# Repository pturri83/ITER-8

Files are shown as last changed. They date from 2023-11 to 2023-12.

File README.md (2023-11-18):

# DB6502 - Dawid Buchwald's 6502 Computer

This repository contains all the work in progress during my build of Ben Eater's inspired 6502 8-bit computer similar to typical machines of the early 1980s. If you haven't seen Ben's videos, I would strongly suggest you start there:

[Ben Eater's 6502 project](https://eater.net/6502)

As stated above, this build is not 100% compatible with what Ben had done - and for a reason, described in next section.

If I had to explain shortly "what it is", the answer would be: simple, yet easy to expand, 8-bit CPU based computer designed and built with one goal only: to use it as a learning and tinkering platform to understand how computers really work. You can use it for simple things like understanding buses, clock cycles, instruction execution, but it also demonstrates more complex concepts like interrupts, interfaces to external components and device handling. More on that below. Everything, hopefully, is simple enough to wrap your head around by one person in couple of weeks.

## Why build something different

[Ben's videos](https://www.youtube.com/playlist?list=PLowKtXNTBypFbtuVMUVXNR0z1mu7dp7eH) on 6502 computer are absolutely awesome - it's one of the best sources in the whole Internet explaining how any computer works. The build he introduced is probably sufficient for most of the things you might ever want to build, and yet I decided to deviate from his design.

The rationale behind this project is pretty simple - the best way to test your understanding of certain subject is to try to expand on what you have learned. You never know if you understood something until you test it by introducing changes to original design - and I used this approach in this project to learn a lot. It was my first proper electronics project, so I would like to apologize for any mistakes. If you think something is off or could have been done differently - please go ahead and raise issue for the repo! All improvements are welcome!

## Why would you bother using DB6502 instead of BE6502

Basically, it gives you almost all the flexibility of Ben's buid without the hassle of breadboard connections for the critical components. You can still run all of Ben's programs (using second VIA port), but the days of looking for loose wire between RAM and CPU are over :) You can, obviously, still experiment with peripherals and breadboard connections using extension port and second VIA.

On top of that you get additional features like extra screen (via onboard connector), keyboard for more versatile input and finally all-in-one serial over USB terminal. You also get easy to use software ready to be installed on the machine to jumpstart your tinkering. When using bootloader you don't even have to flash the EEPROM more than once!

**Important note:** All of the content here is, and always will be open source and free to use, and I don't intend to make any profit out of it. The only way I get anything at all (and it's only small commission to be used for future PCBWay orders) is when you order my boards from PCBWay using the links posted below, but you are welcome to grab these gerber files and order the boards from another provider, or even from PCBWay, just by uploading gerbers to your account, if you don't want me to get the commission :)

## What is different

Compared to Ben's 6502 build I introduced the following changes:

1. Added [automatic power-up reset circuitry](Schematics/README.md#automatic-power-on-reset),
2. Changed [address decoder logic](Schematics/README.md#address-decoder-change) (**very important from compatibility perspective**),
3. Changed [LCD interface](Schematics/README.md#lcd-interface-change) from 8-bit to 4-bit (**very important from compatibility perspective**),
4. Added [additional VIA chip](Schematics/README.md#extra-via-chip) to provide easy expansion of the system,
5. Added [ACIA chip for serial communication](Schematics/README.md#extra-acia-chip-for-serial-communication),
6. Added (**optional - more on that later**) [USB-UART interface](Schematics/README.md#extra-usb-uart-interface-chip) for easy connectivity with PC,
7. Added [PS/2 keyboard port and ATtiny4313-based keyboard controller](Schematics/README.md#ps2-keyboard-interface-and-attiny4313-based-controller) to provide proper replacement for five pushbuttons in Ben's design,
8. Added [expansion port](Schematics/README.md#expansion-port) (not really deviation from Ben's build, save for one detail - unlike Ben's build, my version can support various interrupt sources, including the expansion port),
9. Modified [clock module](Schematics/README.md#modified-clock-module) (external),
10. Changed [compilator from VASM to CC65](Schematics/README.md#migration-from-vasm-to-cc65),
11. Added [simple way to choose clock source](Schematics/README.md#clock-input).

You might be wondering if this means that you can't run Ben's programs on DB6502 - and the answer is **YES YOU CAN**. Indeed, some changes to the code are necessary, but thanks to the additional VIA chip and with some changes to the addressing mode you can run any program from Ben's videos. If you want to use LCD in 8-bit mode, you can also use the additional VIA for it, ignoring the built-in LCD connector.

By the way, the opposite is also true - **you can compile and run my programs on Ben's computer**. There are special compilation flags that enable usage of Ben's address decoder. I will describe this in more detail in software section.

Detailed description and rationale for each change is discussed in [Schematics README](Schematics/README.md).

## Getting started

Okay, so it should be pretty clear what this project is about, so how to start playing with it? That really depends on what you decide to do:

- Stick with BE6502 and just use subset of provided software (either to install it in EEPROM, or just use it as reference for your own hacking),
- Build your own breadboard design based on this one with any modifications you can think of,
- Order PCBs of DB6502, solder the components and run provided software to see how it works and get started with your own designs.

To start from scratch it's actually easiest to select last option - after some waiting you will end up having pretty solid base to extend your design on.

### Using provided software with BE6502

If you decide to go down that route, head straight to the `Software` folder, where you will find several programs either identical or similar to what Ben has shown in his videos, but built with much more versatile toolchain.

If you want to read more, go ahead and read [Software folder](Software/README.md) section. Make sure to check out the [building software](Software/README.md#building-software) subsection, as it explains how to compile programs to run on BE6502 directly.

### Build your own breadboard design

Maybe you have already started expanding on Ben's build, or maybe you are just considering it now. If you want to check out how I did certain things, jump right into `Schematics` [folder](Schematics/README.md), where you will find KiCAD projects for all the components used in this project. Obviously the most important one is the `65C02_Computer` project, but there are some additional goodies there.

**Please note:** This part is not very well documented, I have assumed that anybody willing to dig into these schematics already knows how to read them.

Most of the decisions made during the schematic design were explained above. Justification for anything not covered here can be probably found in the [invaluable 6502 primer](http://wilsonminesco.com/6502primer/).

### Using my PCB design

This will be explained in the most detail, obviously. Start with getting [the PCBs](Schematics/README.md#ordering-pcb). **Please note:** clock module is entirely optional, but really useful for single stepping or slow clocking required by Ben Eater's design of Arduino Mega based bus analyzer. As explained in number of places here, you can either order PCBs from PCBWay directly or use your manufacturer of choice - it should have no impact on the final result.

## What's in the repo

Everything, basically. Schematics of the 6502 board, modified clock module, address decoder and other circuits I built during the project. Arduino sketches I used for debugging and simple programs used to test different features.

And, last but not least, full set of sample programs to follow Ben's videos on DB6502 plus my own bootloader/OS. The last two things are coming soon :)

### `Arduino` folder

There are several sketches there, and their full description is available is [separate README](Arduino/README.md).

### `AVR` folder

There are several projects there, used to experiment with pure `avr-gcc` development for Atmel AVR chips. While it has been interesting adventure that I plan to explore further in the future, it was easier to stick to standard Arduino tools for now and simply restructure code to work there.

### `Datasheets` folder

All the datasheets I used when designing DB6502, attached for reference.

### `Schematics` folder

All the KiCAD schematics for the 6502 computer, modified clock module and several others:

- 65C02_Computer - main schematic, including PCB design for DB6502 computer,
- Clock_module - schematic for the modified clock module, including PCB design,
- 555_troubleshoot - schematic of circuit used in [troubleshooting of clock module monostable noise issue](https://www.reddit.com/r/beneater/comments/edp1ls/noise_issue_in_monostable_mode_of_ben_eaters/),
- Address_decoder_basic - schematic of Ben Eater's address decoder for 6502 project,
- Address_decoder_basic_v2 - slightly modified version of the above,
- Address_decoder_extended - schematic of my own address decoder, used in the DB6502 computer.

There is dedicated [README](Schematics/README.md) in the folder, containing all the build-related details.

### `Software` folder

This one is the most important folder, as it contains range of different programs to play with the 6502 computer. Large subset of this programs can be built for Ben Eater's version of the 6502 computer without any changes. Some of them, however, use features available only in DB6502, like ACIA or keyboard connector. These can still be ran on Ben Eater's 6502 computer, assuming that compatible hardware is added to it.

The `Software` folder is currently divided into four main parts:

- `build` - temporary folder where all the build artifacts are created, including ROM binaries to be uploaded to EEPROM,
- `common` - common sources: include files with common constants, sources with shared function, configuration files for different address decoder logic modes, shared makefile used by all projects and small python script to optimize size of loadable modules,
- `rom` - set of projects used to create various ROM images to follow Ben's videos, test different features of the board and **some day** complete operating system for the computer,
- `load` - set of project containing loadable modules. These can be uploaded at runtime, without the need to flash the EEPROM. Basic bootloader is required, obviously, and the usage instructions are provided below.

There is also one "master" makefile located directly in the `Software` folder - it will build all the projects in `rom` and `load` subfolders.

There is dedicated [README](Software/README.md) in the folder, containing all the software-related details.

## Credits

This project would not be possible if not inspiration, support and help from many, many people:

- [Ben Eater](https://eater.net) - his videos inspired me to learn all this,
- [Dirk Grappendorf](https://grappendorf.net) - awesome documentation of his own 6502 project,
- [Wilson Mines Co.](http://wilsonminesco.com) - the best source of 6502-related information,
- [Dane Creek Photography](https://github.com/danecreekphotography) - for all his support and test driving the project,
- [u/transistorykris](https://www.reddit.com/user/transitorykris/) - his [KrisOS](https://github.com/transitorykris/krisos) is a great inspiration for my own OS development,
- [r/beneater community](https://www.reddit.com/r/beneater/) - for all the great ideas, feedback, creative spirit and exceptional support.

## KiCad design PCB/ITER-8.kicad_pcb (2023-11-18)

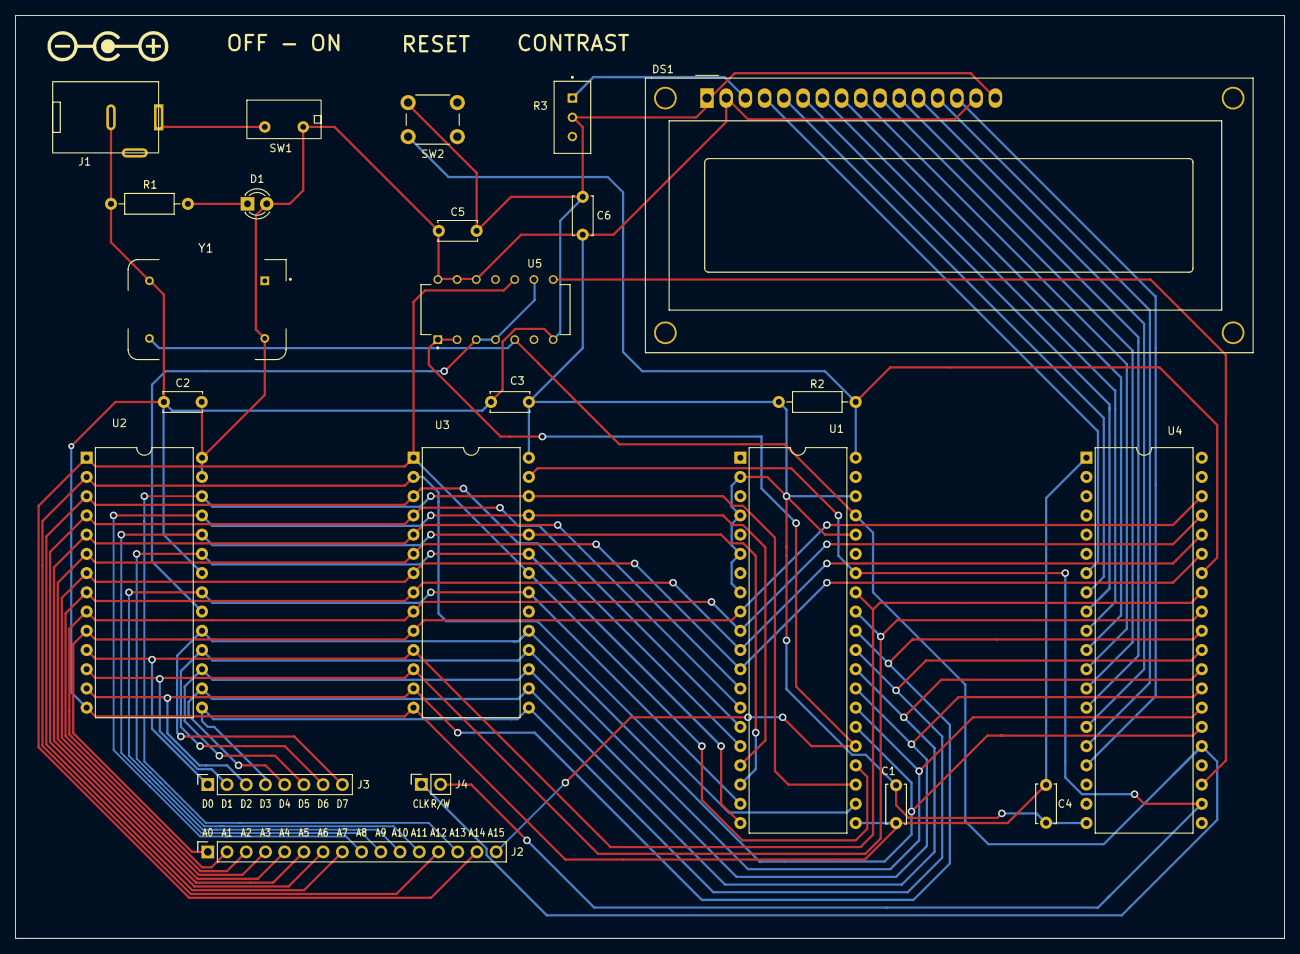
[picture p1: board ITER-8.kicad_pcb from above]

Board: 2 copper layers, 167.6 x 121.9 mm, 23 parts (0 on the bottom side), 46 nets.

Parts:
C1, C2, C3, C4, C5, C6: 100n; C_Disc_D5.0mm_W2.5mm_P5.00mm
D1: LED; LED_D3.0mm
DS1: LCD-016M002B; WC1602A
J1: DC-005
J2: Conn_01x16; PinSocket_1x16_P2.54mm_Vertical
J3: Conn_01x08; PinSocket_1x08_P2.54mm_Vertical
J4: Conn_01x02; PinSocket_1x02_P2.54mm_Vertical
R1: 150R; R_Axial_DIN0207_L6.3mm_D2.5mm_P10.16mm_Horizontal
R2: 1k; R_Axial_DIN0207_L6.3mm_D2.5mm_P10.16mm_Horizontal
R3: 3296-W; TRIM_3296-W
SW1: A11JP
SW2: Dual Push Button; SW_PUSH_double_6mm
U1: W65C02S6TPG-14; DIP-40_W15.24mm
U2: AT28C256-15PU; DIP-28_W15.24mm
U3: AS6C62256-55PCN; DIP-28_W15.24mm
U4: W65C22SxP; DIP-40_W15.24mm
U5: SN74HC00N; DIP794W45P254L1969H508Q14
Y1: ECS-100AX-010; OSC_ECS-100AX-010

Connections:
+5V: J1.1, SW1.1 (A)
/A0: J2.1, U1.9 (A0), U2.10 (A0), U3.10 (A0), U4.38 (RS0)
/A1: J2.2, U1.10 (A1), U2.9 (A1), U3.9 (A1), U4.37 (RS1)
/A2: J2.3, U1.11 (A2), U2.8 (A2), U3.8 (A2), U4.36 (RS2)
/A3: J2.4, U1.12 (A3), U2.7 (A3), U3.7 (A3), U4.35 (RS3)
/A4: J2.5, U1.13 (A4), U2.6 (A4), U3.6 (A4)
/A5: J2.6, U1.14 (A5), U2.5 (A5), U3.5 (A5)
/A6: J2.7, U1.15 (A6), U2.4 (A6), U3.4 (A6)
/A7: J2.8, U1.16 (A7), U2.3 (A7), U3.3 (A7)
/A8: J2.9, U1.17 (A8), U2.25 (A8), U3.25 (A8)
/A9: J2.10, U1.18 (A9), U2.24 (A9), U3.24 (A9)
/A10: J2.11, U1.19 (A10), U2.21 (A10), U3.21 (A10)
/A11: J2.12, U1.20 (A11), U2.23 (A11), U3.23 (A11)
/A12: J2.13, U1.22 (A12), U2.2 (A12), U3.2 (A12)
/A13: J2.14, U1.23 (A13), U2.26 (A13), U3.26 (A13), U4.24 (CS1)
/A14: J2.15, U1.24 (A14), U2.1 (A14), U3.1 (A14), U3.22 (~OE), U5.10 (3B)
/A15: J2.16, U1.25 (A15), U5.1 (1A), U5.2 (1B)
/D0: J3.1, U1.33 (D0), U2.11 (D0), U3.11 (Q0), U4.33 (D0)
/D1: J3.2, U1.32 (D1), U2.12 (D1), U3.12 (Q1), U4.32 (D1)
/D2: J3.3, U1.31 (D2), U2.13 (D2), U3.13 (Q2), U4.31 (D2)
/D3: J3.4, U1.30 (D3), U2.15 (D3), U3.15 (Q3), U4.30 (D3)
/D4: J3.5, U1.29 (D4), U2.16 (D4), U3.16 (Q4), U4.29 (D4)
/D5: J3.6, U1.28 (D5), U2.17 (D5), U3.17 (Q5), U4.28 (D5)
/D6: J3.7, U1.27 (D6), U2.18 (D6), U3.18 (Q6), U4.27 (D6)
/D7: J3.8, U1.26 (D7), U2.19 (D7), U3.19 (Q7), U4.26 (D7)
/PA5: DS1.4 (RS), U4.7 (PA5)
/PA6: DS1.5 (R/W), U4.8 (PA6)
/PA7: DS1.6 (E), U4.9 (PA7)
/PB0: DS1.7 (D0), U4.10 (PB0)
/PB1: DS1.8 (D1), U4.11 (PB1)
/PB2: DS1.9 (D2), U4.12 (PB2)
/PB3: DS1.10 (D3), U4.13 (PB3)
/PB4: DS1.11 (D4), U4.14 (PB4)
/PB5: DS1.12 (D5), U4.15 (PB5)
/PB6: DS1.13 (D6), U4.16 (PB6)
/PB7: DS1.14 (D7), U4.17 (PB7)
GND: C1.1, C2.1, C3.1, C4.1, C5.2, C6.2, DS1.1 (VSS), DS1.16 (LED(-)), J1.2, R1.1, R3.2, SW2.2, U1.21 (VSS), U2.14 (GND), U2.22 (~OE), U3.14 (GND), U4.1 (VSS), U5.7 (GND), Y1.7 (CASE_GND)
unnamed: C1.2, C2.2, C3.2, C4.2, C5.1, C6.1, D1.2 (A), DS1.2 (VDD), DS1.15 (LED(+)), R2.1, SW1.2 (B), U1.2 (RDY), U1.4 (~IRQ), U1.6 (~NMI), U1.8 (VDD), U1.36 (BE), U1.38 (~SO), U2.27 (~WE), U2.28 (VCC), U3.28 (VCC), U4.20 (VCC), U5.12 (4A), U5.13 (4B), U5.14 (VCC), Y1.14 (+VDC)
unnamed: D1.1 (K), R1.2
unnamed: DS1.3 (VO), R3.1
unnamed: J4.1, U1.37 (ϕ0), U4.25 (ϕ2), U5.5 (2B), Y1.8 (OUTPUT)
unnamed: J4.2, U1.34 (R/~W), U3.27 (~WE), U4.22 (R/~W)
unnamed: R2.2, SW2.1, U1.40 (~RES), U4.34 (~RES)
unnamed: U2.20 (~CS), U5.3 (1Y), U5.4 (2A), U5.9 (3A)
unnamed: U3.20 (~CS), U5.6 (2Y)
unnamed: U4.23 (~CS2), U5.8 (3Y)

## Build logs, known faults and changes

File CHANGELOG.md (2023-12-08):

# Changelog

Notable changes to ITER-8 are recorded here.

## Current Release - [0.3] - 2023-12-07

### Added

- Bulk capacitor in the power module.
- Push button to generate an interrupt.
- Test #3 for handling an interrupt request.
- Automatic reset when powering.

### Changed

- Reset button on the breadboard has been moved near the power button.
- Improved schematics layout.

## [0.2] - 2023-11-30

### Added

- This changelog.
- Assembly subroutine to wait for a number of milliseconds.

### Changed

- Schematics are split into sub-assemblies. A peripherals page has been added.
- LCD operation is in 4-bit mode.
- Names of many assembly macros and subroutines.
- Several assembly macros changed to subroutines.
- Standardized assembly docstrings.

### Moved

- Breadboard file.

### Removed

- Files included in `.gitignore`.

## [0.1] - 2023-11-18

### Added

- This release.

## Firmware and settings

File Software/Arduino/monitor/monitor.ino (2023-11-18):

/*
    Monitor address and data pins

    Print in the serial monitor the A0-A15 address and D0-D7 data values of a W65C02S microprocessor at each clock cycle.
    The data line outputs its value in binary, hexadecimal, and OpCode. A marker is shown when either the RESET vector or a NOP instruction is hit.
    The clock module can be stopped automatically when a NOP instruction is reached.

    Created on 2023-09-14
    By Paolo Turri
*/

// Settings parameters
const bool HALT = true;   // Halt the clock module if NOP is detected

// Pins parameters
const int CLOCK_PIN = 2;    // Arduino pin connected to the clock signal
const int RW_PIN = 3;    // Arduino pin connected to the W65C02S read/write pin
const int HALT_PIN = 4;    // Arduino pin connected to the clock module's halt pin
const int ADDR_PINS[] = {52, 50, 48, 46, 44, 42, 40, 38, 36, 34, 32, 30, 28, 26, 24, 22};   // Arduino pins connected to W65C02S A0-A15, in reverse orderOpCodes
const int DATA_PINS1[] = {53, 51, 49, 47, 45, 43, 41, 39};   // Arduino pins connected to W65C02S D0-D7, in reverse order
const int DATA_PINS2[] = {37, 35, 33, 31, 29, 27, 25, 23};   // Arduino pins connected to a second data set, in reverse order

// Instructions arrays
const int INSTR_OPC[] = {0x00, 0x01, 0x04, 0x05, 0x06, 0x07, 0x08, 0x09, 0x0A, 0x0C, 0x0D, 0x0E, 0x0F,
                         0x10, 0x11, 0x12, 0x14, 0x15, 0x16, 0x17, 0x18, 0x19, 0x1A, 0x1C, 0x1D, 0x1E, 0x1F,
                         0x20, 0x21, 0x24, 0x25, 0x26, 0x27, 0x28, 0x29, 0x2A, 0x2C, 0x2D, 0x2E, 0x2F,
                         0x30, 0x31, 0x32, 0x34, 0x35, 0x36, 0x37, 0x38, 0x39, 0x3A, 0x3C, 0x3D, 0x3E, 0x3F,
                         0x40, 0x41, 0x45, 0x46, 0x47, 0x48, 0x49, 0x4A, 0x4C, 0x4D, 0x4E, 0x4F,
                         0x50, 0x51, 0x52, 0x55, 0x56, 0x57, 0x58, 0x59, 0x5A, 0x5D, 0x5E, 0x5F,
                         0x60, 0x61, 0x64, 0x65, 0x66, 0x67, 0x68, 0x69, 0x6A, 0x6C, 0x6D, 0x6E, 0x6F,
                         0x70, 0x71, 0x72, 0x74, 0x75, 0x76, 0x77, 0x78, 0x79, 0x7A, 0x7C, 0x7D, 0x7E, 0x7F,
                         0x80, 0x81, 0x84, 0x85, 0x86, 0x87, 0x88, 0x89, 0x8A, 0x8C, 0x8D, 0x8E, 0x8F,
                         0x90, 0x91, 0x92, 0x94, 0x95, 0x96, 0x97, 0x98, 0x99, 0x9A, 0x9C, 0x9D, 0x9E, 0x9F,
                         0xA0, 0xA1, 0xA2, 0xA4, 0xA5, 0xA6, 0xA7, 0xA8, 0xA9, 0xAA, 0xAC, 0xAD, 0xAE, 0xAF,
                         0xB0, 0xB1, 0xB2, 0xB4, 0xB5, 0xB6, 0xB7, 0xB8, 0xB9, 0xBA, 0xBC, 0xBD, 0xBE, 0xBF,
                         0xC0, 0xC1, 0xC4, 0xC5, 0xC6, 0xC7, 0xC8, 0xC9, 0xCA, 0xCB, 0xCC, 0xCD, 0xCE, 0xCF,
                         0xD0, 0xD1, 0xD2, 0xD5, 0xD6, 0xD7, 0xD8, 0xD9, 0xDA, 0xDB, 0xDD, 0xDE, 0xDF,
                         0xE0, 0xE1, 0xE4, 0xE5, 0xE6, 0xE7, 0xE8, 0xE9, 0xEA, 0xEC, 0xED, 0xEE, 0xEF,
                         0xF0, 0xF1, 0xF2, 0xF5, 0xF6, 0xF7, 0xF8, 0xF9, 0xFA, 0xFD, 0xFE, 0xFF};  // Instruction OpCodes
const char* INSTR_NAME[] = {"BRK", "ORA", "TSB", "ORA", "ASL", "RMB0", "PHP", "ORA", "ASL", "TSB", "ORA", "ASL", "BBR0",
                            "BPL", "ORA", "ORA", "TRB", "ORA", "ASL", "RMB1", "CLC", "ORA", "INC", "TRB", "ORA", "ASL", "BBR1",
                            "JSR", "AND", "BIT", "AND", "ROL", "RMB2", "PLP", "AND", "ROL", "BIT", "AND", "ROL", "BBR2",
                            "BMI", "AND", "AND", "BIT", "AND", "ROL", "RMB3", "SEC", "AND", "DEC", "BIT", "AND", "ROL", "BBR3",
                            "RTI", "EOR", "EOR", "LSR", "RMB4", "PHA", "EOR", "LSR", "JMP", "EOR", "LSR", "BBR4",
                            "BVC", "EOR", "EOR", "EOR", "LSR", "RMB5", "CLI", "EOR", "PHY", "EOR", "LSR", "BBR5",
                            "RTS", "ADC", "STZ", "ADC", "ROR", "RMB6", "PLA", "ADC", "ROR", "JMP", "ADC", "ROR", "BBR6",
                            "BVS", "ADC", "ADC", "STZ", "ADC", "ROR", "RMB7", "SEI", "ADC", "PLY", "JMP", "ADC", "ROR", "BBR7",
                            "BRA", "STA", "STY", "STA", "STZ", "SMB0", "DEY", "BIT", "TXA", "STY", "STA", "STX", "BBS0",
                            "BCC", "STA", "STA", "STY", "STA", "STZ", "SMB1", "TYA", "STA", "TSX", "STZ", "STA", "STZ", "BBS1",
                            "LDY", "LDA", "LDX", "LDY", "LDA", "LDX", "SMB2", "TAY", "LDA", "TAX", "LDY", "LDA", "LDX", "BBS2",
                            "BCS", "LDA", "LDA", "LDY", "LDA", "LDX", "SMB3", "CLV", "LDA", "TSX", "LDY", "LDA", "LDX", "BBS3",
                            "CPY", "CMP", "CPY", "CMP", "DEC", "SMB4", "INY", "CMP", "DEX", "WAI", "CPY", "CMP", "DEC", "BBS4",
                            "BNE", "CMP", "CMP", "CMP", "DEC", "SMB5", "CLD", "CMP", "PHX", "STP", "CMP", "DEC", "BBS5",
                            "CPX", "SBC", "CPX", "SBC", "INC", "SMB6", "INX", "SBC", "NOP", "CPX", "SBC", "INC", "BBS6",
                            "BEQ", "SBC", "SBC", "SBC", "INC", "SMB7", "SED", "SBC", "PLX", "SBC", "INC", "BBS7"};  // Instruction names


// Clock interrupt
void onClock()
{

  // Monitor address pins
  int addr = 0;

  for (int i = 0; i < 16; i++) {
    int bit = (digitalRead(ADDR_PINS[i]) ? 1 : 0);   // Read the pin bit
    Serial.print(bit);
    addr = (addr << 1) + bit;    // Add the bit to the address
  }

  Serial.print("    ");


  // Monitor data pins
  int data = 0;

  for (int i = 0; i < 8; i++) {
    int bit = (digitalRead(DATA_PINS1[i]) ? 1 : 0);   // Read the pin bit
    Serial.print(bit);
    data = (data << 1) + bit;    // Add the bit to the data
  }

  Serial.print("    ");

  // Monitor read/write pin
  char rw = (digitalRead(RW_PIN) ? 'R' : 'W');

  // Print hexadecimal values
  char hex[20];
  sprintf(hex, "    %c    %04X    %02X", rw, addr, data);
  Serial.print(hex);

  // Print instruction
  int instr_len = sizeof(INSTR_OPC) / sizeof(int);
  int instr_flag = false;
  Serial.print("    ");

  for (int i = 0; i < instr_len; i++) {

    if (data == INSTR_OPC[i]) {
      instr_flag = true;
      Serial.print(INSTR_NAME[i]);
    }
  }

  if (not instr_flag) {
    Serial.print("---");
  }

  // Print bookmark
  if (data == 0xEA) {  // NOP OpCode
    Serial.print("   ---> BOOKMARK");
  }

  // Print reset
  if (addr == 0xFFFC) {  // Reset vector address
    Serial.print("   ---> RESET");
  }

  Serial.println("");

  // Halt clock
  if (HALT && (data == 0xEA)) {  // NOP OpCode
    digitalWrite(HALT_PIN, HIGH);   // Set high
  }
}


// Setup
void setup()
{
  // Serial port
  Serial.begin (9600);   // Set speed
  delay(2000);  // Wait for the serial port
  Serial.println("\n\n\n\n\n\n\n\n\n\n\n\n\n\n\n\n\n\n\n\n==================================================\n");  // Clear screen

  // Clock pin
  pinMode(CLOCK_PIN, INPUT_PULLUP);
  attachInterrupt(digitalPinToInterrupt(CLOCK_PIN), onClock, RISING);   // Attach an interrupt

  // Read/write pin
  pinMode(RW_PIN, INPUT_PULLUP);   // Set as input

  // Halt pin
  pinMode(HALT_PIN, OUTPUT);   // Set as output
  digitalWrite(HALT_PIN, LOW);   // Set low
  
  // Address pins
  for (int i = 0; i < 16; i++) {
    pinMode(ADDR_PINS[i], INPUT_PULLUP);   // Set as input
  }

  // Data pins
  for (int i = 0; i < 8; i++) {
    pinMode(DATA_PINS1[i], INPUT);   // Set as input
  }
}


// Loop
void loop()
{
}

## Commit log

2023-11-18 Test 1 & 2
    First and second test roms, with related scripts, diagrams, and layouts.
    [ITER-8.fzz, ITER-8_v1.kicad_pcb, ITER-8_v1.kicad_sch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]
2023-11-30 4-bit LCD
    LCD in 4-bit mode, including assembly subroutines for timings. New test of the division with remainder.
    [ITER-8.fzz, ITER-8.kicad_pcb, ITER-8.kicad_sch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]
2023-12-08 Button interrupt
    New test to count the number of interrupts from a push button. The power section has been changed to automatically reset the computer.
    [ITER-8.fzz, ITER-8.kicad_sch, ITER-8_peripherals.kicad_sch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]
